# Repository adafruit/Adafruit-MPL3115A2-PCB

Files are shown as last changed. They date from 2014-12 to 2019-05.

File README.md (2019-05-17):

# Adafruit MPL3115A2 I2C Barometric Pressure/Altitude/Temperature Sensor PCB
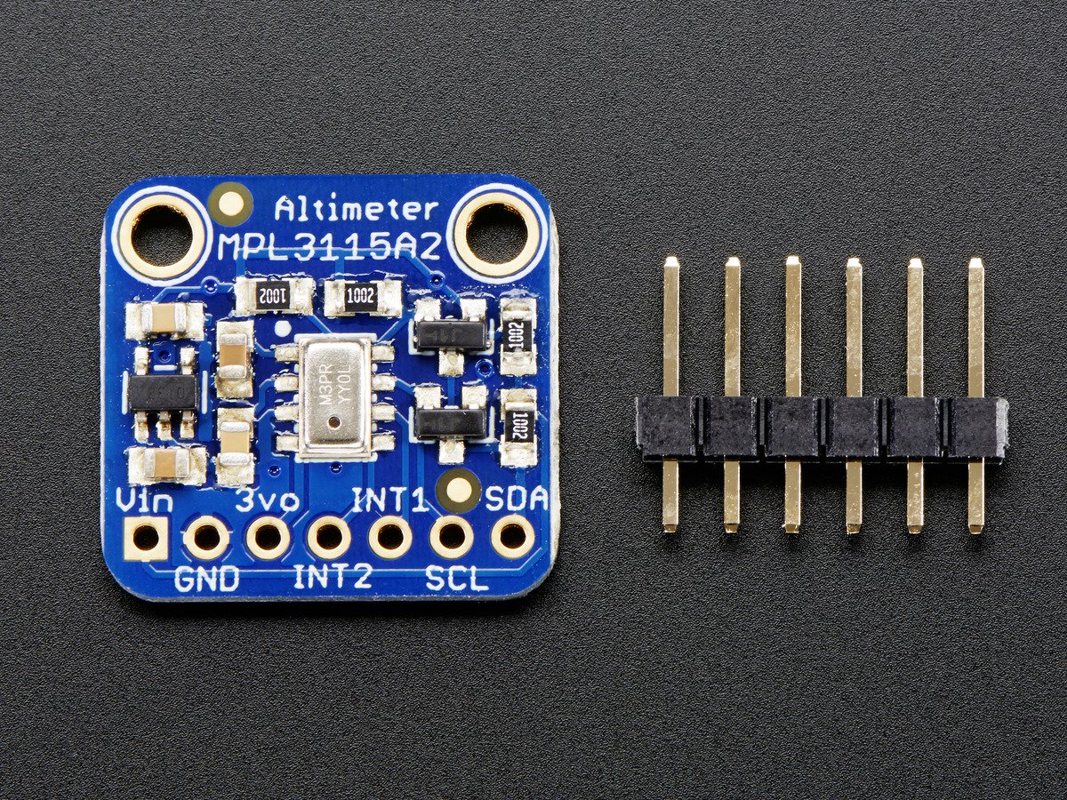
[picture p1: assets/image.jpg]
<a href="http://www.adafruit.com/products/1893"><br/>
Click here to purchase one from the Adafruit shop</a>

This pressure sensor from Freescale is a great low-cost sensing solution for precision measurement of barometric pressure and altitude. The MPL3115A2 has a typical 1.5 Pascal resolution, which can resolve altitude at 0.3 meters (compare to the BMP180 which can do 0.17m). It has some upsides compared to the BMP280, such as interrupt outputs for ultra-low power usage, and its also a heck of a lot easier to read altitude with a built in altimeter calculation - no calibration reading and calculating required. As a bonus, there's even a fairly good temperature sensor with ±1°C typical accuracy (±3°C max).

These are the Eagle CAD files for the Adafruit MPL3115A2 Barometric 
Pressure/Temperature/Altitude Sensor
. 
For more details, check out the product page at

-----> https://www.adafruit.com/product/1893

### License

Adafruit invests time and resources providing this open source design, please support Adafruit and open-source hardware by purchasing products from [Adafruit](https://www.adafruit.com)!

All text above must be included in any redistribution

Designed by Limor Fried/Ladyada for Adafruit Industries.
Creative Commons Attribution/Share-Alike, all text above must be included in any redistribution. 
See license.txt for additional information.

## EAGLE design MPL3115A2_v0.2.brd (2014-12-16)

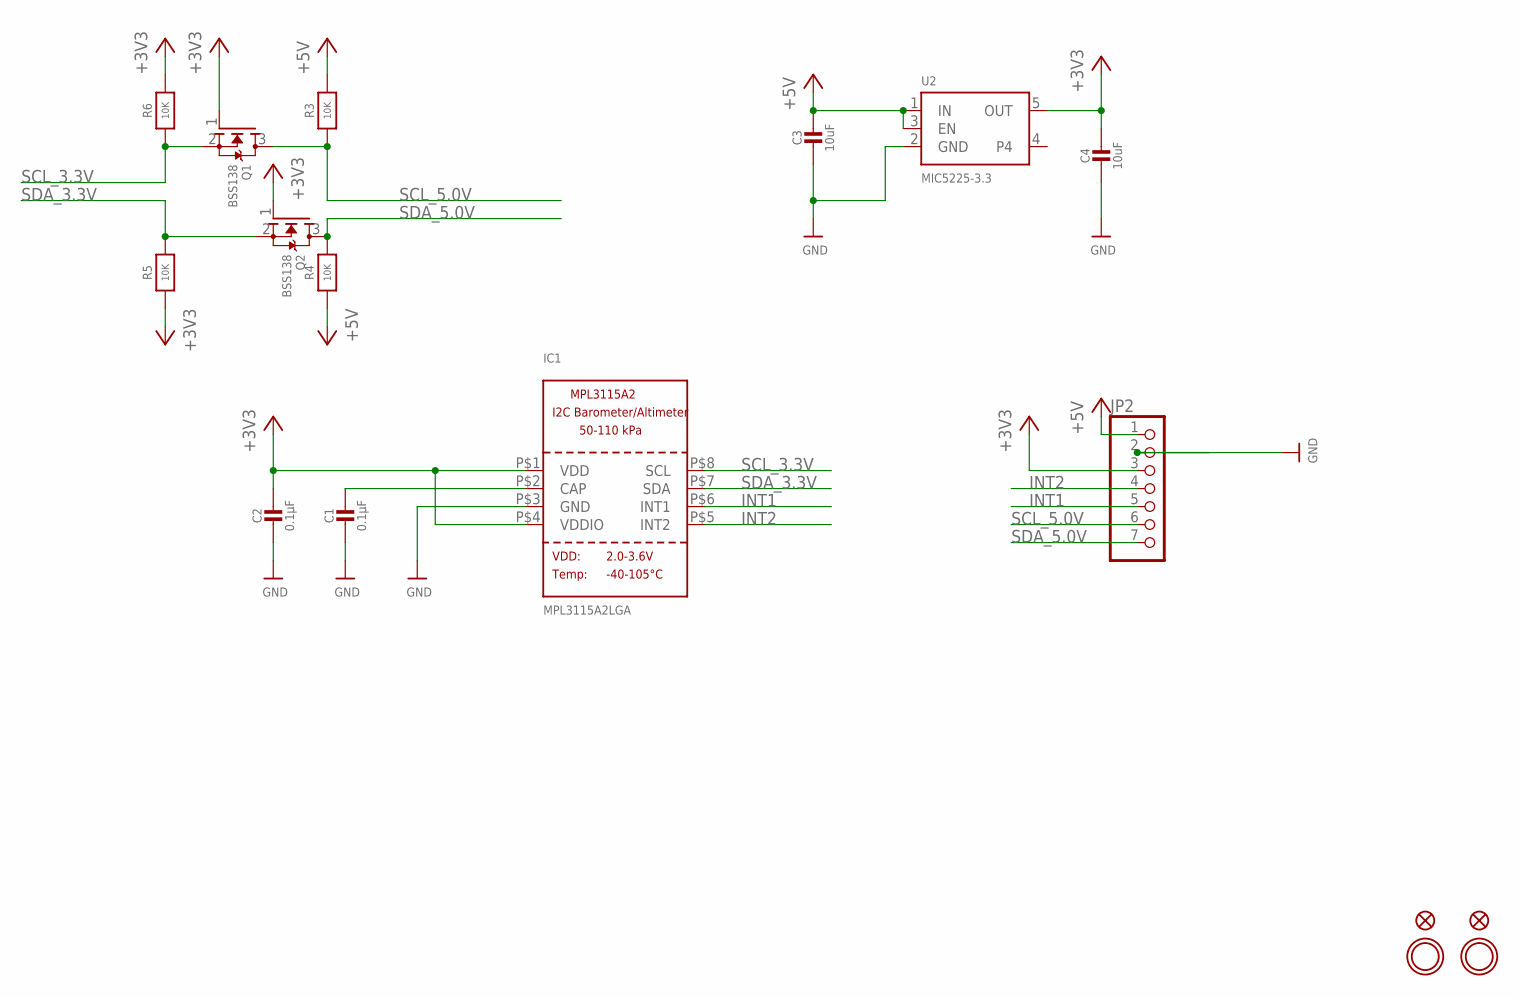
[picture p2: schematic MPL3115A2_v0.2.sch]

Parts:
C1, C2: 0.1µF; 0805-NO
C3, C4: 10uF; 0805-NO
FID1, FID2: FIDUCIAL""; FIDUCIAL_1MM
IC1: MPL3115A2LGA; LGA8
JP2: HEADER-1X770MIL; 1X07_ROUND_70
Q1, Q2: BSS138; SOT23-WIDE
R3, R4, R5, R6: 10K; 0805-NO
U2: MIC5225-3.3; SOT23-5
U$8, U$9: MOUNTINGHOLE2.5; MOUNTINGHOLE_2.5_PLATED

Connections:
+3V3: C2.1, C4.1, IC1.P$1 (VDD), IC1.P$4 (VDDIO), JP2.3, Q1.1 (G), Q2.1 (G), R5.1, R6.2, U2.5 (OUT)
+5V: C3.1, JP2.1, R3.2, R4.1, U2.1 (IN), U2.3 (EN)
CAP: C1.1, IC1.P$2 (CAP)
GND: C1.2, C2.2, C3.2, C4.2, IC1.P$3 (GND), JP2.2, U2.2 (GND)
INT1: IC1.P$6 (INT1), JP2.5
INT2: IC1.P$5 (INT2), JP2.4
SCL_3.3V: IC1.P$8 (SCL), Q1.2 (S), R6.1
SCL_5.0V: JP2.6, Q1.3 (D), R3.1
SDA_3.3V: IC1.P$7 (SDA), Q2.2 (S), R5.2
SDA_5.0V: JP2.7, Q2.3 (D), R4.2

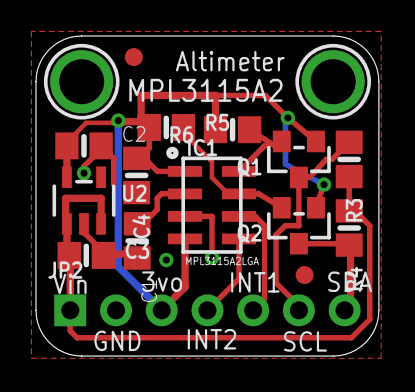
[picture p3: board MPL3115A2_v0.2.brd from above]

Board: 2 copper layers, 19.1 x 17.8 mm, 18 parts (1 on the bottom side), 10 nets.

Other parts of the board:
U$14: ADAFRUIT_3.5MM

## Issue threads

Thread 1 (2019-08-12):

Hole spacing not mentioned anywhere

tkircher, 2019-08-12:
I was hoping to find the hole spacing for this sensor, but it isn't mentioned anywhere on the Adafruit website. So for anyone else who's interested, I pulled the values from the Eagle CAD file: The holes are 2.5mm, spaced 13.97mm apart (0.55 inches). Please at least update the documentation here to include these critical dimensions.
